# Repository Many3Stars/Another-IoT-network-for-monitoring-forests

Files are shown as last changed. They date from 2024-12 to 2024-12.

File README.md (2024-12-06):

# IoT Monitoring System for Forest Environments

Author: Manuel Álvarez Herrera  
Supervisor: José Antonio García Souto  
Year: 2024

## Abstract

This project implements an IoT system to monitor forest environments, particularly coniferous and oak forests, aiming to study the effects of climate change. The IoT network consists of sensor nodes, intermediate nodes, and a database, enabling the collection and analysis of environmental and tree health data.

## Objectives

The primary objective is to observe the impact of climate change on trees by collecting relevant data such as temperature, humidity, solar radiation, and other key indicators.

## Technologies Used

- **Hardware:** Arduino, Raspberry Pi, Dragino NBSN95, LSN50, temperature, humidity sensors, and more.
- **Communication Protocols:** LoRa, NB-IoT, WiFi.
- **Databases:** InfluxDB, ThingsBoard, Home Assistant.
- **Weather Stations:** Ecowitt, Wunderground, Weathercloud.

## IoT Network Structure

1. **Sensor Node A:** Arduino Uno, Raspberry Pi 4 B, sensors for foliage and soil.
2. **Sensor Node B:** Dragino NBSN95 and LSN50 devices.
3. **Sensor Node C:** Sainlogic WS3500 weather station.

## Results

The system was successfully tested in a controlled environment, obtaining accurate data for forest environment analysis. The tests demonstrated the system's viability for monitoring remote forests.

## Conclusion

The designed IoT system is scalable, energy-efficient, and adaptable to various environments, including farms and urban forest areas.

## Repository

The code and additional documentation are available in the following GitHub repository:  
[Another IoT network for monitoring forests](https://github.com/Many3Stars/IoT-network-for-monitoring-forests)

## References

1. K. Raviteja, M. Supriya, "IoT-Based Agriculture Monitoring System", Springer, 2020.
2. N. Suma, S. Samson, "Recent Innovations in Computing and Communication", 2021.
3. Kazuho M., Takeshi O., "Dependence of Stomatal Conductance on Leaf Chlorophyll Concentration", 2025.

---

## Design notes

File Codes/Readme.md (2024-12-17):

# Codes

This directory contains the source codes for the two types of sensor nodes used in the IoT monitoring system for forest environments: **Sensor Node A** and **Sensor Node B**. These nodes handle data acquisition, preprocessing, and transmission to the IoT network.

---

## Sensor Nodes Overview

### **Sensor Node A**
- **Functionality:** 
  - This node is designed to acquire and process data from various sensors.
  - The sensors are connected to an Arduino Uno, which handles data acquisition and preprocessing.
  - The processed data is then transmitted to a Raspberry Pi 4 B, which:
    - Powers the sensors.
    - Temporarily stores the data in a JSON file.
    - Transmits the data via LoRa communication to the IoT network.
- **Communication Protocol:** LoRa (long-range, low-power communication).
- **Use Case:** Suitable for applications requiring robust communication over long distances in remote environments.

### **Sensor Node B**
- **Functionality:**
  - This node uses Dragino devices (NBSN95 and LSN50) for data acquisition, preprocessing, and transmission.
  - Each device serves a specific purpose:
    - **NBSN95:** Transmits data via NB-IoT, leveraging GSM networks for mobile communication.
    - **LSN50:** Transmits data via LoRa for long-distance communication.
  - These nodes are compact and support plug-and-play operation, ideal for rapid deployment.
- **Communication Protocols:** 
  - NB-IoT (NBSN95)
  - LoRa (LSN50)
- **Use Case:** Versatile for environments with varying communication infrastructure.

---

## Folder Structure

### **Sensor_Node_A**
- Contains the source code for Sensor Node A.
- Key Features:
  - Arduino sketch for data acquisition and preprocessing.
  - Raspberry Pi scripts for:
    - JSON-based temporary data storage.
    - Transmission using LoRa communication.
  - Power management routines for efficient operation.

### **Sensor_Node_B**
- Contains the source code for Sensor Node B.
- Key Features:
  - Firmware for Dragino NBSN95 and LSN50 devices.
  - Configurations for sensor data acquisition and transmission.
  - NB-IoT and LoRa-specific implementations for data handling.

---

## How to Use

1. **Select the Appropriate Node:**
   - Use **Sensor Node A** for scenarios requiring detailed control via Arduino and Raspberry Pi.
   - Use **Sensor Node B** for rapid deployment with Dragino devices.

2. **Upload the Code:**
   - For Sensor Node A:
     - Upload the Arduino sketch to the Arduino Uno.
     - Deploy the Raspberry Pi scripts.
   - For Sensor Node B:
     - Configure and upload the firmware to the NBSN95 and LSN50 devices.

3. **Test the Nodes:**
   - Verify sensor data acquisition and preprocessing.
   - Ensure successful data transmission via the appropriate protocol (LoRa or NB-IoT).

---

## Notes

- Ensure all hardware components are correctly connected and powered before uploading the code.
- Customize the configuration files as needed for your specific sensors and deployment environment.
- Detailed instructions for setting up and calibrating the nodes can be found in the respective subfolders.

---

## Support

If you encounter issues or have questions:
- Refer to the comments in the code for additional guidance.
- Open an issue in this repository or contact the repository maintainer for further assistance.

---

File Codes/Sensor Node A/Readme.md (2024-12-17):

# Sensor Node A

This folder contains the code and configurations for **Sensor Node A**, which is responsible for data acquisition, preprocessing, and transmission in the IoT monitoring system for forest environments.

---

## Overview

**Sensor Node A** integrates two primary components:

1. **Arduino Uno**:  
   - Acquires and preprocesses data from connected sensors (e.g., soil and leaf sensors).  
   - Processes sensor readings and prepares them for transmission.  
   - Communicates with the Raspberry Pi via I2C.

2. **Raspberry Pi 4 B**:  
   - Receives the preprocessed data from the Arduino over an I2C connection.  
   - Temporarily stores the data in a JSON format.  
   - Transmits the data to the IoT network using an external LoRa communication module.

This architecture ensures efficient handling of data while leveraging the long-range capabilities of LoRa communication for remote deployments.

---

## Key Features

- **I2C Communication**:  
  The Arduino sends preprocessed sensor data to the Raspberry Pi via an I2C interface, ensuring a reliable and simple data transfer method.

- **LoRa Transmission**:  
  The Raspberry Pi uses an external LoRa module to transmit the collected data over long distances. This is ideal for remote environments with limited connectivity.

- **Power Management**:  
  The system includes routines to minimize power consumption, such as turning off sensors when not in use.

---

## Folder Structure

- `arduino/`: Contains the Arduino sketch for:
  - Data acquisition from sensors.
  - Preprocessing and sending data to the Raspberry Pi via I2C.

- `raspberry_pi/`: Contains Python scripts for:
  - Receiving data over I2C.
  - Formatting and storing data in JSON files.
  - Transmitting data using the external LoRa communication module.

---

## How to Use

1. **Arduino Setup**:
   - Open the Arduino sketch from the `arduino/` folder.
   - Upload it to the Arduino Uno.
   - Ensure sensors are properly connected to the Arduino.

2. **Raspberry Pi Setup**:
   - Install the necessary Python dependencies listed in the `requirements.txt` (if provided).
   - Run the Raspberry Pi scripts to:
     - Initialize the I2C connection.
     - Manage data storage and LoRa transmission.

3. **Hardware Connections**:
   - Connect the Arduino and Raspberry Pi via I2C:
     - **Arduino SDA (A4)** → **Raspberry Pi SDA (GPIO2)**  
     - **Arduino SCL (A5)** → **Raspberry Pi SCL (GPIO3)**  
   - Ensure the LoRa module is properly connected to the Raspberry Pi.

4. **Run the System**:
   - Power on the devices and verify that:
     - The Arduino is acquiring sensor data and sending it over I2C.
     - The Raspberry Pi is successfully receiving the data and transmitting it via LoRa.

---

## Notes

- The external LoRa module must be configured correctly for the desired frequency and region.
- Ensure that both the Arduino and Raspberry Pi share a common ground (GND) for proper I2C communication.

---

## Troubleshooting

- **No I2C Communication:** 
  - Verify SDA and SCL connections.
  - Ensure the I2C interface is enabled on the Raspberry Pi.

- **LoRa Transmission Issues:** 
  - Check the LoRa module configuration and ensure it matches the receiver settings.
  - Verify the antenna is securely attached to the LoRa module.

---

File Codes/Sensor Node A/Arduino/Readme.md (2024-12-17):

# Arduino

This folder contains the Arduino sketches used in **Sensor Node A** for data acquisition and preprocessing. The sketches are designed to support two operation modes: continuous data acquisition (Mode 1) and periodic data acquisition with advanced averaging techniques (Mode 2).

---

## Modes of Operation

### **Mode 1: Continuous Data Acquisition**
- **Description**:
  - In this mode, the Arduino continuously powers the sensors and acquires data without interruption.
  - The Raspberry Pi remains active and periodically requests the acquired data via I2C.
- **Use Case**:
  - Ideal for scenarios requiring real-time or near-real-time monitoring.

### **Mode 2: Periodic Data Acquisition with Power Management**
- **Description**:
  - In this mode, the system enters a low-power state between data acquisition intervals.
  - The Raspberry Pi powers down the sensors and itself, then wakes up periodically to acquire data.
  - Data is processed using either a **Trimmed Mean** or a **Winsorized Mean** to reduce the impact of noise and outliers.
  - After processing, the Arduino sends the data to the Raspberry Pi over I2C, and the Raspberry Pi transmits it using LoRa.
- **Use Case**:
  - Ideal for power-constrained environments where energy efficiency is critical.

---

## Arduino Sketches

1. **Mode_1_Continuous_Data_Acquisition.ino**
   - Implements continuous data acquisition.
   - The Arduino constantly acquires data from the sensors.
   - Responds to requests from the Raspberry Pi to send the data via I2C.

2. **Mode_1_Data_Acquisition_when_it_receives_request_from_Rasp.ino**
   - Similar to the first sketch, but data acquisition is triggered only when the Raspberry Pi sends a request.
   - Useful for reducing unnecessary sensor activity.

3. **Mode_2_Periodic_Acquisition_Trimmed_Mean.ino**
   - Implements periodic data acquisition with power management.
   - Processes acquired data using a **Trimmed Mean**, which discards extreme values to reduce the influence of outliers.

4. **Mode_2_Periodic_Acquisition_Winsorized_Mean.ino**
   - Similar to the previous sketch but processes data using a **Winsorized Mean**, which limits extreme values to reduce noise while retaining the original data structure.

---

## How It Works

1. **Sensor Activation**:
   - In **Mode 1**, sensors are always powered.
   - In **Mode 2**, sensors are activated only during the data acquisition period.

2. **Data Processing**:
   - The Arduino preprocesses the sensor data using the selected mode:
     - Continuous data stream (Mode 1).
     - Trimmed or Winsorized mean calculation (Mode 2).

3. **I2C Communication**:
   - The Arduino sends the processed data to the Raspberry Pi via I2C upon request.

4. **LoRa Transmission**:
   - The Raspberry Pi handles the transmission of the processed data via LoRa.

---

## How to Use

1. **Select the Desired Mode**:
   - Choose the appropriate sketch based on your use case (continuous or periodic data acquisition).

2. **Upload the Sketch**:
   - Open the selected `.ino` file in the Arduino IDE.
   - Upload it to the Arduino Uno.

3. **Configure the Raspberry Pi**:
   - Ensure the Raspberry Pi is configured to match the selected mode:
     - **Mode 1**: Continuous or on-request data acquisition.
     - **Mode 2**: Periodic data collection with power management.

4. **Test the System**:
   - Verify sensor readings and data transmission.
   - Check that the Raspberry Pi and Arduino communicate properly over I2C.

---

## Notes

- **Power Efficiency**:
  - Mode 2 significantly reduces power consumption by deactivating sensors and the Raspberry Pi between acquisition cycles.
  - Use this mode for long-term deployments in remote areas.

- **Data Integrity**:
  - Advanced processing methods (Trimmed and Winsorized Means) in Mode 2 ensure robust data quality by minimizing the impact of noise and outliers.

---

## Troubleshooting

- **I2C Communication Issues**:
  - Verify the wiring between the Arduino and Raspberry Pi (SDA/SCL connections).
  - Ensure the Raspberry Pi's I2C interface is enabled.

- **Unexpected Data Values**:
  - Check sensor connections and calibration.
  - Validate the averaging method used in Mode 2.

---

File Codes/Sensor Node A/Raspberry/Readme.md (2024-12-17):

 # Raspberry

This folder contains the scripts and configurations used by the Raspberry Pi in **Sensor Node A**. The Raspberry Pi plays a crucial role in managing data communication between the Arduino and the IoT network.

---

## Functionality

The Raspberry Pi handles the following tasks:

1. **Requesting Data from Arduino**:  
   - The Raspberry Pi sends periodic requests to the Arduino over the I2C interface.  
   - The Arduino responds with the preprocessed sensor data.

2. **Storing Data in JSON Format**:  
   - The received data is stored locally in a JSON file as a backup.  
   - This ensures data is not lost if the LoRa connection fails temporarily.

3. **Transmitting Data via LoRa**:  
   - The Raspberry Pi uses an external LoRa communication module to send the sensor data to the IoT network.  
   - LoRa provides long-range, low-power communication ideal for remote monitoring.

--- 

## How It Works

1. **I2C Communication**:
   - The Raspberry Pi acts as an I2C master, sending requests to the Arduino (I2C slave).
   - Data exchange format:
     - **Request:** A simple command from the Raspberry Pi to trigger data transmission.
     - **Response:** The Arduino sends sensor readings in a structured format.

2. **Data Backup**:
   - After receiving the data, the Raspberry Pi writes it to a local JSON file.
   - This file acts as a backup, allowing recovery of data if the LoRa transmission fails.

3. **LoRa Transmission**:
   - The Raspberry Pi formats the data for LoRa transmission.
   - It sends the data using the external LoRa module, ensuring it reaches the IoT network even in remote environments.

---

## Notes

- **Backup and Resilience**:
  - JSON backups ensure data integrity in case of transmission failures.
  - These files can be uploaded manually to the IoT network if needed.

- **LoRa Module**:
  - Ensure the LoRa module is configured correctly for the region and frequency.
  - Check that the antenna is securely attached for optimal signal strength.

---

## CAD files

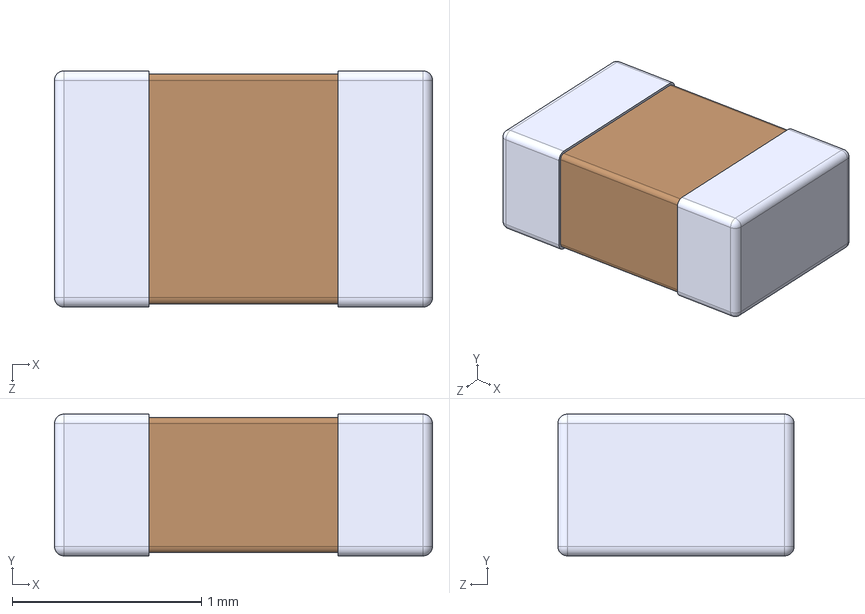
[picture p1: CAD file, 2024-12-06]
PCB_Manufacturing_Sheets/Components/CL21B103KBANNNC/CL21B103KBANNNC.step
2.00 x 0.75 x 1.25 mm

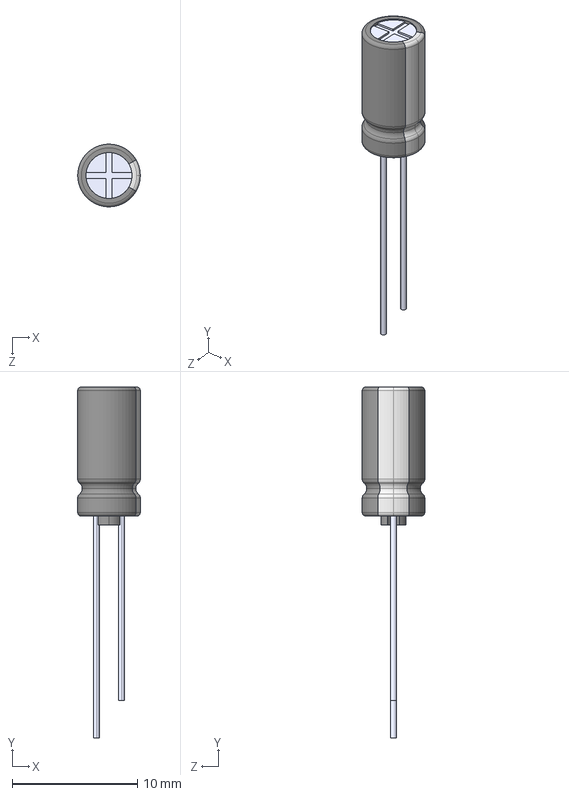
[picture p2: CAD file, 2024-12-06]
PCB_Manufacturing_Sheets/Components/EEUFC1H150/EEU-FC1H150.STEP
5.00 x 28.0 x 4.99 mm

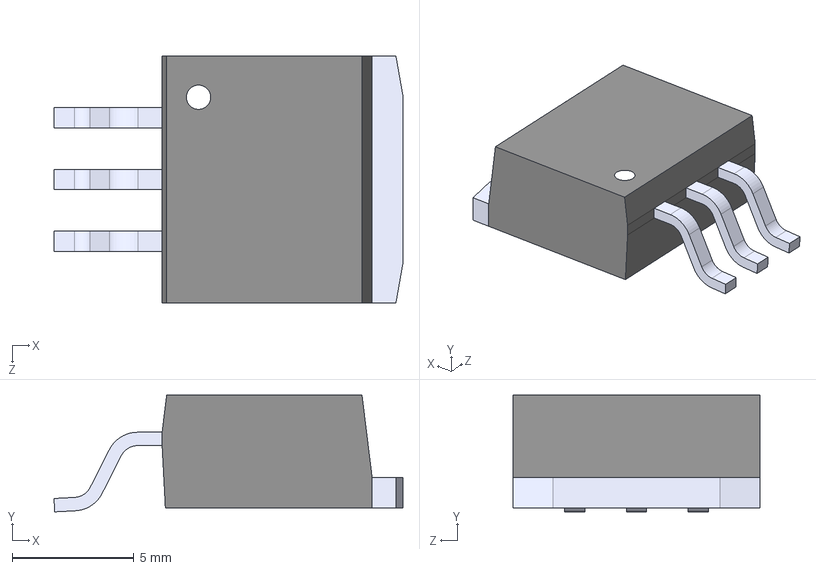
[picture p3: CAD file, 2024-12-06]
PCB_Manufacturing_Sheets/Components/LM1085ISX-5.0_NOPB/LM1085ISX-5.0_NOPB.step
14.4 x 4.80 x 10.2 mm

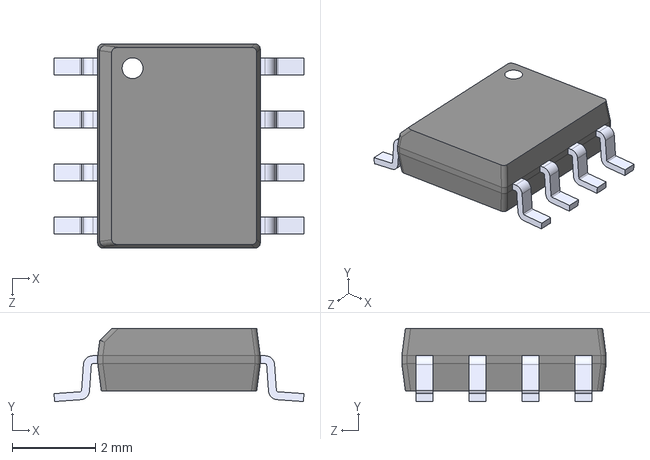
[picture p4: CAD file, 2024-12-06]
PCB_Manufacturing_Sheets/Components/LM317LID/LM317LID.step
5.99 x 1.75 x 4.90 mm

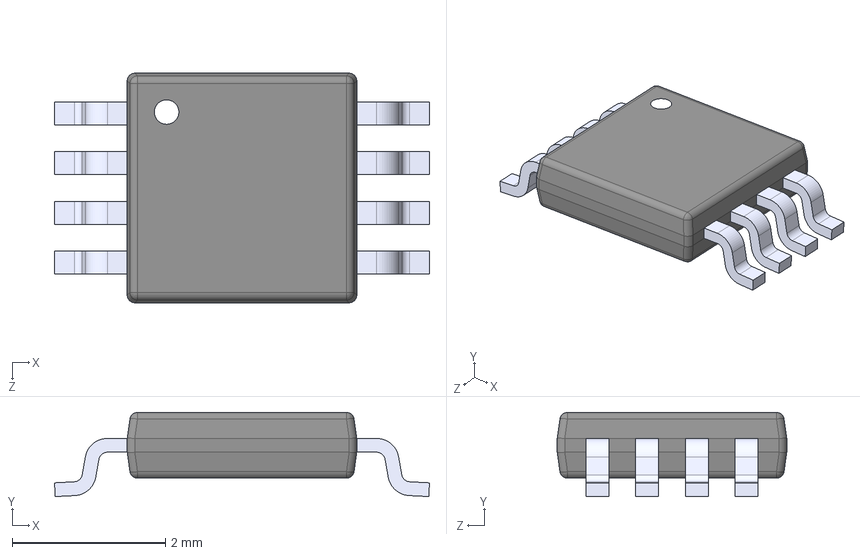
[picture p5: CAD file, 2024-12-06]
PCB_Manufacturing_Sheets/Components/LT5400BCMS8E-6_PBF/LT5400BCMS8E-6_PBF.step
4.90 x 1.10 x 3.00 mm

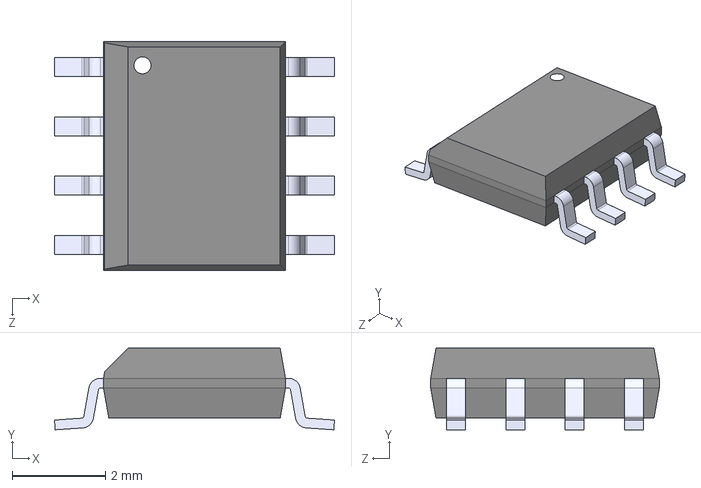
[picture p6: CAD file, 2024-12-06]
PCB_Manufacturing_Sheets/Components/OP292GSZ-REEL/OP292GSZ-REEL.step
6.00 x 1.75 x 4.90 mm

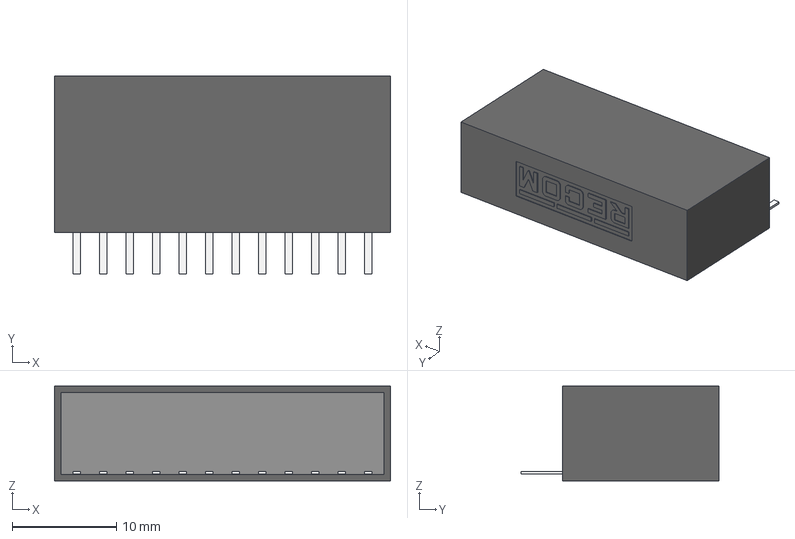
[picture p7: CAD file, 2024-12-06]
PCB_Manufacturing_Sheets/Components/R-739.0P/R-739.0P.step
32.2 x 19.0 x 9.10 mm

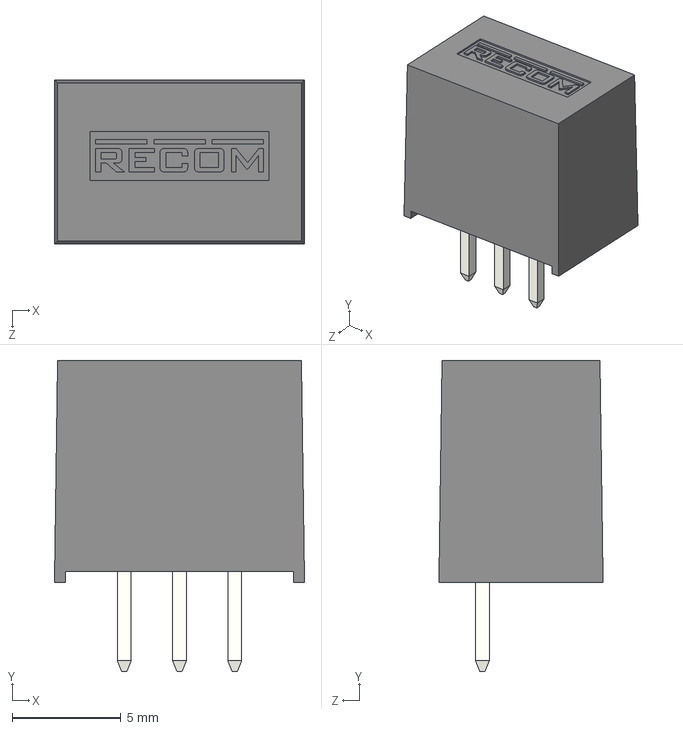
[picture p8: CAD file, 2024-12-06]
PCB_Manufacturing_Sheets/Components/R-78K2.5-1.0/R-78K2.5-1.0.step
11.5 x 14.3 x 7.55 mm

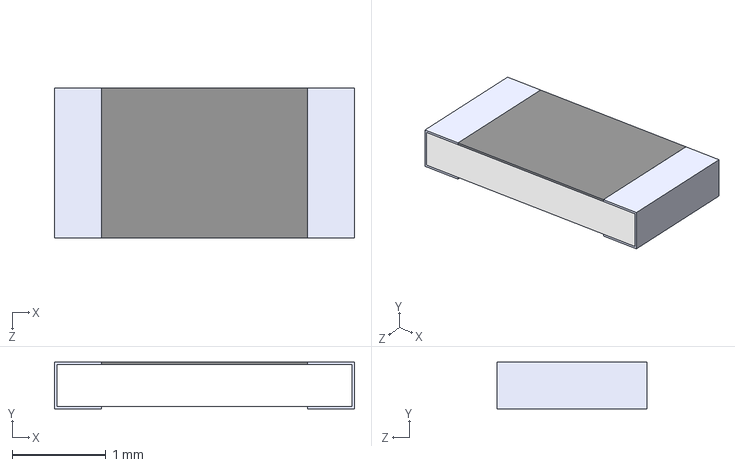
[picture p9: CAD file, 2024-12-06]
PCB_Manufacturing_Sheets/Components/RG3216P-1000-B-T1/RG3216P-1000-B-T1.step
3.20 x 0.5 x 1.60 mm

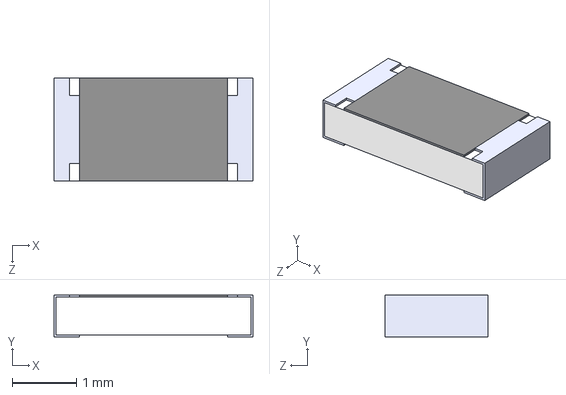
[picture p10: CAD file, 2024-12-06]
PCB_Manufacturing_Sheets/Components/RT1206BRD07300RL/RT1206BRD07300RL.step
3.10 x 0.65 x 1.60 mm

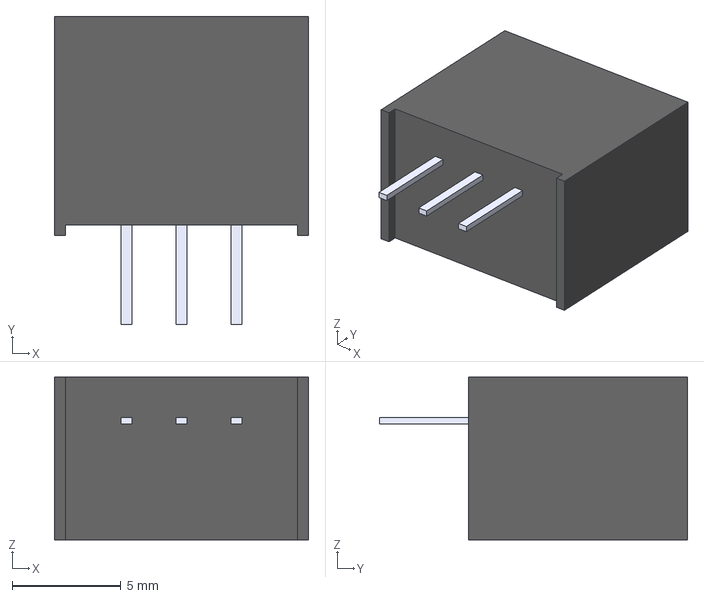
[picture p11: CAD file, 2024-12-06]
PCB_Manufacturing_Sheets/Components/VR05S(TSR1-2490)/TSR1-2490.step
11.7 x 14.2 x 7.50 mm

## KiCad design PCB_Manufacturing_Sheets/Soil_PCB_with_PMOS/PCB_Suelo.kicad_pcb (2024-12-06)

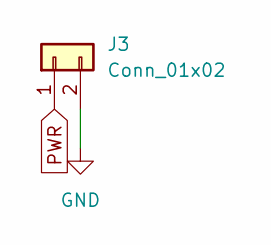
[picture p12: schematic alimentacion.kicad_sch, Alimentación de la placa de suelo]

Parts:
J3: Conn_01x02; PinHeader_1x02_P2.54mm_Vertical

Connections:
GND: J3.2; also elsewhere on the board
PWR: J3.1; also elsewhere on the board

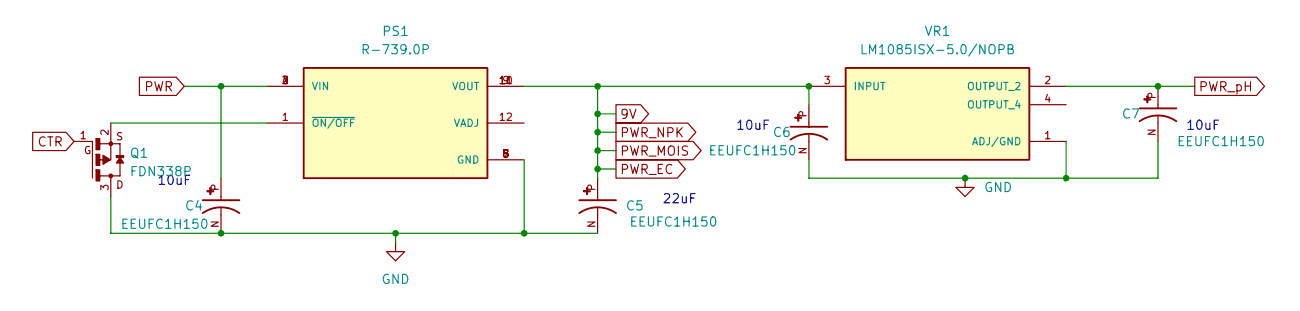
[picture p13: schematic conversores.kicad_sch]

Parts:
C4, C5, C6, C7: EEUFC1H150; CAPPRD200W50D500H1100; PARTREV 20-DEC-19
PS1: R-739.0P; CONV_R-739.0P; PARTREV 5
Q1: FDN338P; SSOT-3
VR1: LM1085ISX-5.0/NOPB; TO254P1435X464-4N; PARTREV I

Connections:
9V: C5.P, C6.P, PS1.9 (VOUT), PS1.10 (VOUT), PS1.11 (VOUT), VR1.3 (INPUT); also elsewhere on the board
CTR: Q1.1; also elsewhere on the board
GND: C4.N, C5.N, C6.N, C7.N, PS1.5 (GND), PS1.6 (GND), PS1.7 (GND), PS1.8 (GND), Q1.3, VR1.1 (ADJ/GND); also elsewhere on the board
unnamed: PS1.1 (~ON/OFF), Q1.2
PWR: C4.P, PS1.2 (VIN), PS1.3 (VIN), PS1.4 (VIN); also elsewhere on the board
PWR_pH: C7.P, VR1.2 (OUTPUT_2); also elsewhere on the board

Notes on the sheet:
10uF
22uF

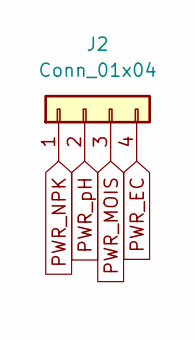
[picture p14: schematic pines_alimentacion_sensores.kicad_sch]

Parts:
J2: Conn_01x04; PinHeader_1x04_P2.54mm_Vertical

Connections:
9V: J2.1, J2.3, J2.4; also elsewhere on the board
PWR_pH: J2.2; also elsewhere on the board

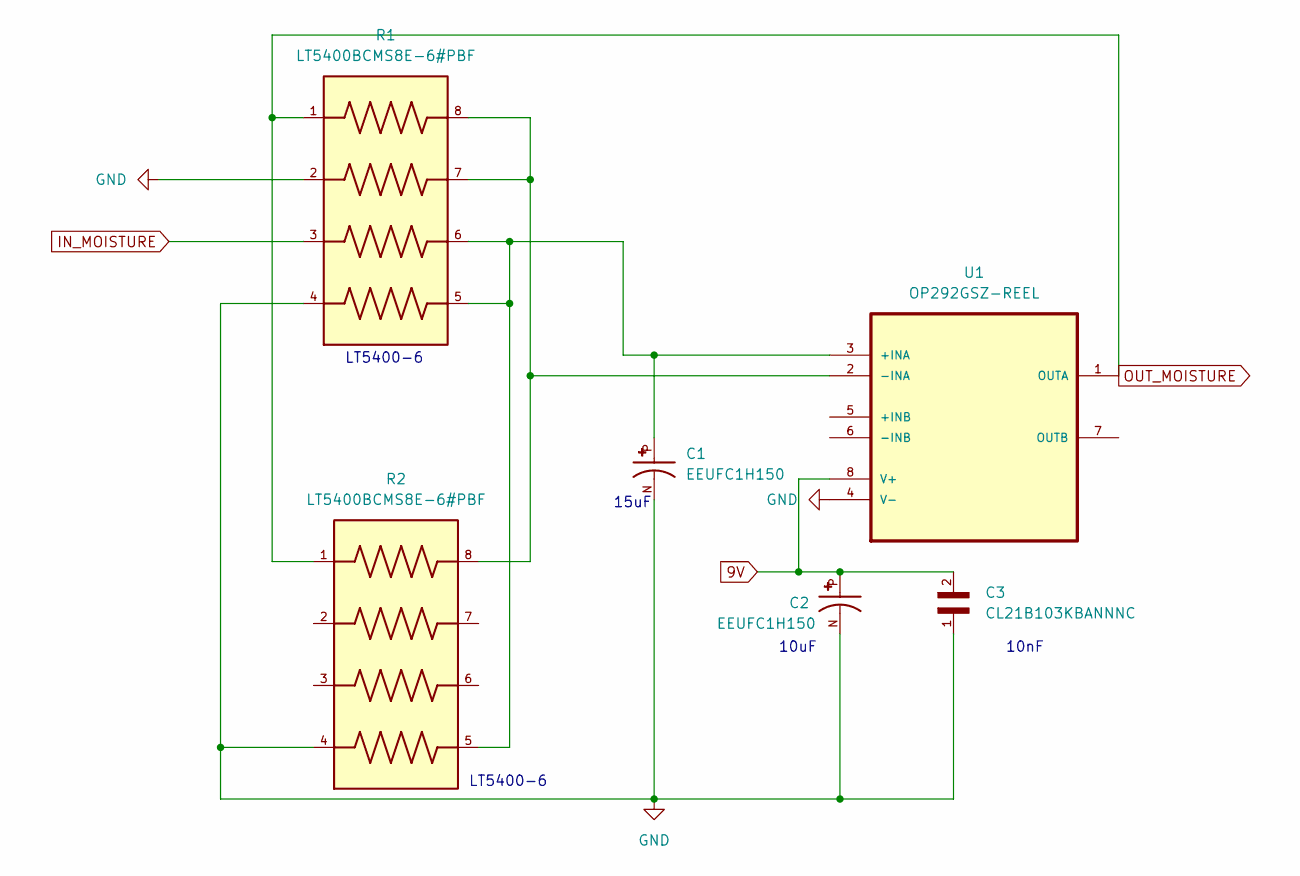
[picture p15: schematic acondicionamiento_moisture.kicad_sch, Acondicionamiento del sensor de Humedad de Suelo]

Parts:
C1, C2: EEUFC1H150; CAPPRD200W50D500H1100; PARTREV 20-DEC-19
C3: CL21B103KBANNNC; CAPC2012X140N
R1, R2: LT5400BCMS8E-6#PBF; SOP65P490X110-9N; PARTREV I
U1: OP292GSZ-REEL; SOIC127P600X175-8N; MPN OP292GSZ-REEL

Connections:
9V: C2.P, C3.2, U1.8 (V+); also elsewhere on the board
GND: C1.N, C2.N, C3.1, R1.2, R1.4, R2.4, U1.4 (V-); also elsewhere on the board
IN_MOISTURE: R1.3; also elsewhere on the board
unnamed: C1.P, R1.5, R1.6, R2.5, U1.3 (+INA)
unnamed: R1.7, R1.8, R2.8, U1.2 (-INA)
OUT_MOISTURE: R1.1, R2.1, U1.1 (OUTA); also elsewhere on the board

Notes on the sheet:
10nF
LT5400-6
10uF
15uF

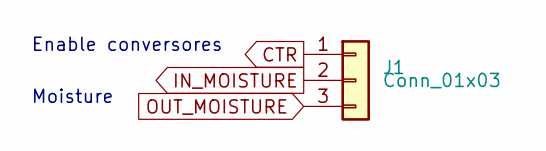
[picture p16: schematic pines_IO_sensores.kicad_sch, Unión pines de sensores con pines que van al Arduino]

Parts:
J1: Conn_01x03; PinHeader_1x03_P2.54mm_Vertical

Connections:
CTR: J1.1; also elsewhere on the board
IN_MOISTURE: J1.2; also elsewhere on the board
OUT_MOISTURE: J1.3; also elsewhere on the board

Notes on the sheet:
Moisture
Enable conversores

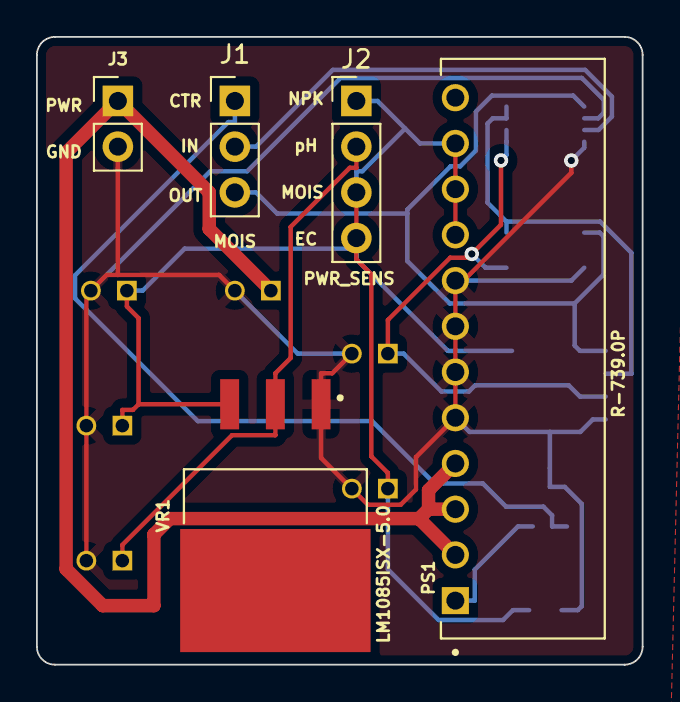
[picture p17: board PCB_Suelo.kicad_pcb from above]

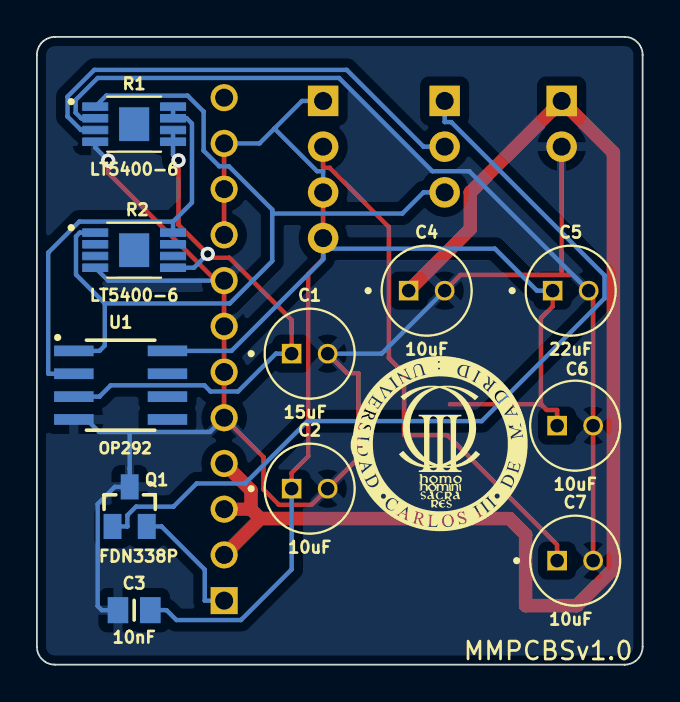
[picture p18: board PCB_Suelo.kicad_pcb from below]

Board: 2 copper layers, 33.7 x 34.9 mm, 17 parts (12 on the bottom side), 10 nets.

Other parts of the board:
G: L; Logo2

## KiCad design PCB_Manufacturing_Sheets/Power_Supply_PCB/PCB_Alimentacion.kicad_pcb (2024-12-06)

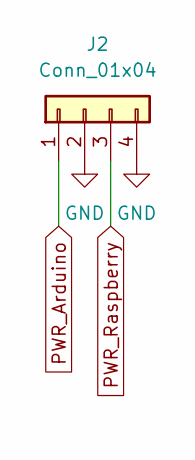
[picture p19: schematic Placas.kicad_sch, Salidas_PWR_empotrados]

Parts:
J2: Conn_01x04; PinHeader_1x04_P2.54mm_Vertical

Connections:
GND: J2.2, J2.4; also elsewhere on the board
PWR_Arduino: J2.1; also elsewhere on the board
PWR_Raspberry: J2.3; also elsewhere on the board

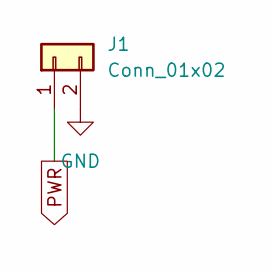
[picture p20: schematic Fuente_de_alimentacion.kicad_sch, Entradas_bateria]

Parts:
J1: Conn_01x02; PinHeader_1x02_P2.54mm_Vertical

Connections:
GND: J1.2; also elsewhere on the board
PWR: J1.1; also elsewhere on the board

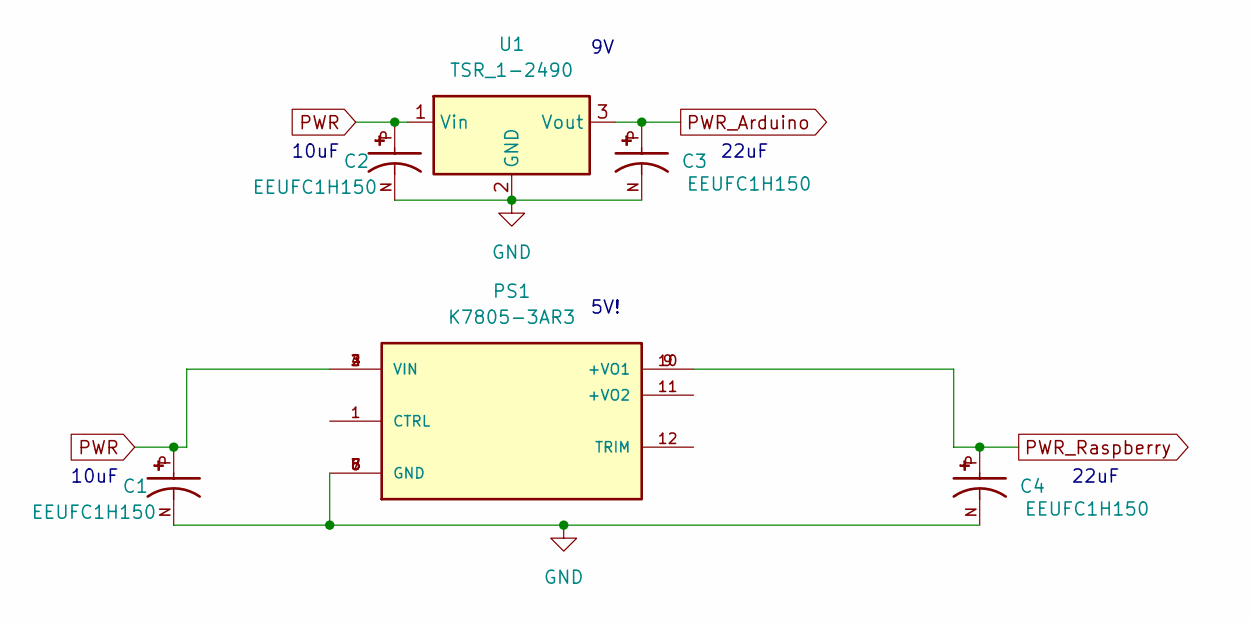
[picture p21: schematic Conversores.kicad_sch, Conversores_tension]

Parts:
C1, C2, C3, C4: EEUFC1H150; CAPPRD200W50D500H1100; PARTREV 20-DEC-19
PS1: K7805-3AR3; CONV_K7805-3AR3; PARTREV 2021.01.29-A/2
U1: TSR_1-2490; Converter_DCDC_TRACO_TSR-1_THT

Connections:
GND: C1.N, C2.N, C3.N, C4.N, PS1.5 (GND), PS1.6 (GND), PS1.7 (GND), PS1.8 (GND), U1.2 (GND); also elsewhere on the board
PWR: C1.P, C2.P, PS1.2 (VIN), PS1.3 (VIN), PS1.4 (VIN), U1.1 (Vin); also elsewhere on the board
PWR_Arduino: C3.P, U1.3 (Vout); also elsewhere on the board
PWR_Raspberry: C4.P, PS1.9 (+VO1), PS1.10 (+VO1); also elsewhere on the board

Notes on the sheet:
22uF
10uF
5V!

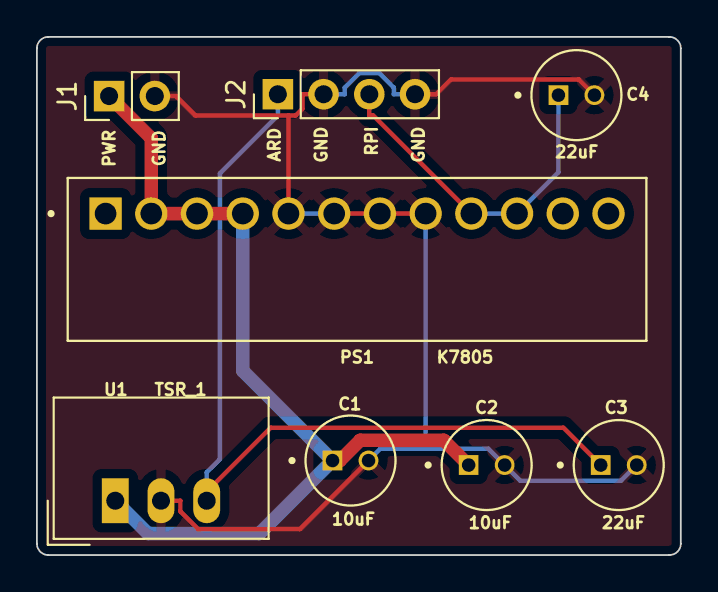
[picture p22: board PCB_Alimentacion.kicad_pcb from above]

Board: 2 copper layers, 35.8 x 28.8 mm, 9 parts (1 on the bottom side), 4 nets.

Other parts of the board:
G: L; Logo2

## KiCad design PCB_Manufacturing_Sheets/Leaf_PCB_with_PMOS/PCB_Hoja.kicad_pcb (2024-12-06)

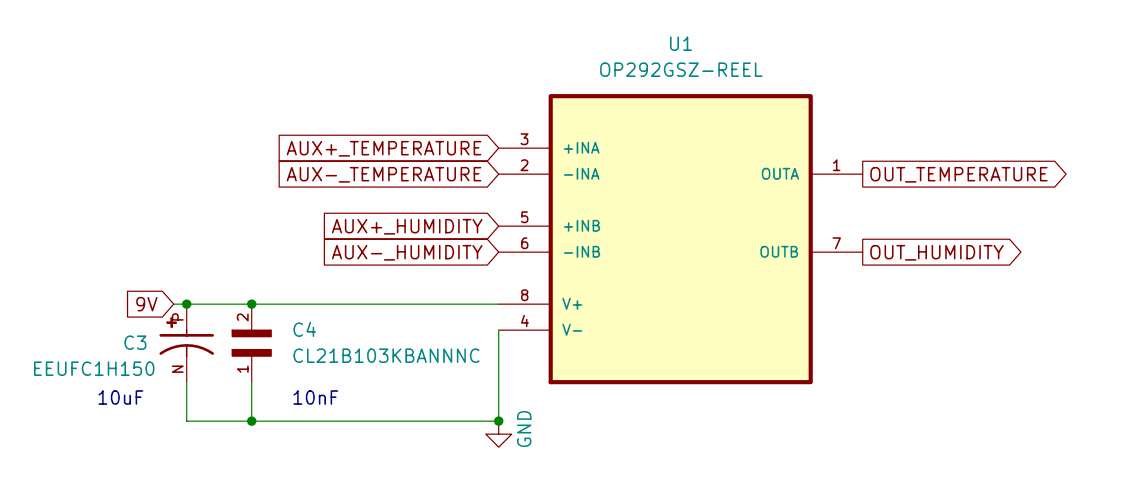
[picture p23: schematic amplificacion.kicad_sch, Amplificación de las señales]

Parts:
C3: EEUFC1H150; CAPPRD200W50D500H1100; PARTREV 20-DEC-19
C4: CL21B103KBANNNC; CAPC2012X140N
U1: OP292GSZ-REEL; SOIC127P600X175-8N; MPN OP292GSZ-REEL

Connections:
9V: C3.P, C4.2, U1.8 (V+); also elsewhere on the board
AUX+_HUMIDITY: U1.5 (+INB); also elsewhere on the board
AUX+_TEMPERATURE: U1.3 (+INA); also elsewhere on the board
AUX-_HUMIDITY: U1.6 (-INB); also elsewhere on the board
AUX-_TEMPERATURE: U1.2 (-INA); also elsewhere on the board
GND: C3.N, C4.1, U1.4 (V-); also elsewhere on the board
OUT_HUMIDITY: U1.7 (OUTB); also elsewhere on the board
OUT_TEMPERATURE: U1.1 (OUTA); also elsewhere on the board

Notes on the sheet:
10nF
10uF


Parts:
J2, J3: Conn_01x02; PinHeader_1x02_P2.54mm_Vertical

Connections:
IN_HUMIDITY: J2.1; also elsewhere on the board
IN_TEMPERATURE: J2.2; also elsewhere on the board
OUT_HUMIDITY: J3.2; also elsewhere on the board
OUT_TEMPERATURE: J3.1; also elsewhere on the board

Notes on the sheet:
Humidity
Temperature


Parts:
C2: EEUFC1H150; CAPPRD200W50D500H1100; PARTREV 20-DEC-19
R3: LT5400BCMS8E-6#PBF; SOP65P490X110-9N; PARTREV I

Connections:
AUX+_HUMIDITY: C2.P, R3.5, R3.6; also elsewhere on the board
AUX-_HUMIDITY: R3.7, R3.8; also elsewhere on the board
GND: C2.N, R3.2, R3.4; also elsewhere on the board
IN_HUMIDITY: R3.3; also elsewhere on the board
OUT_HUMIDITY: R3.1; also elsewhere on the board

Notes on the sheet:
LT5400-7
15uF


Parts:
C5, C6: CL21B103KBANNNC; CAPC2012X140N
R4: LT5400BCMS8E-6#PBF; SOP65P490X110-9N; PARTREV I
U2: LM317LID; SOIC127P599X175-8N
U3: LM358DR2G; SOIC127P600X175-8N

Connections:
0.25V: U3.1 (AOUT), U3.2 (AIN-); also elsewhere on the board
9V: C5.1, U2.1 (IN), U3.8 (VCC); also elsewhere on the board
GND: C5.2, C6.2, R4.2, U2.4 (ADJUSTMENT), U3.4 (GND); also elsewhere on the board
unnamed: C6.1, R4.1, U2.2 (OUT), U2.3 (OUT), U2.6 (OUT), U2.7 (OUT)
unnamed: R4.7, R4.8, U3.3 (AIN+)

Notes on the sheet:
1uF
0.25V
0.1uF
LT5400-7
1.25V


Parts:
C1: CL21B103KBANNNC; CAPC2012X140N
R1, R2: LT5400BCMS8E-6#PBF; SOP65P490X110-9N; PARTREV I

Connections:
0.25V: R1.8; also elsewhere on the board
AUX+_TEMPERATURE: C1.1, R1.6, R2.3, R2.4; also elsewhere on the board
AUX-_TEMPERATURE: R1.7, R2.1, R2.2; also elsewhere on the board
GND: C1.2, R2.5, R2.6; also elsewhere on the board
IN_TEMPERATURE: R1.5; also elsewhere on the board
unnamed: R1.1, R1.2
unnamed: R1.3, R1.4
OUT_TEMPERATURE: R2.7, R2.8; also elsewhere on the board

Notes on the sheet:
LT5400-2
LT5400-1
1uF


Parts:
J4: Conn_01x08; PinHeader_1x08_P2.54mm_Vertical

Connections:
GND: J4.2, J4.4, J4.6, J4.8; also elsewhere on the board
PWR_CO2: J4.3, J4.5, J4.7; also elsewhere on the board
PWR_TEMP: J4.1; also elsewhere on the board

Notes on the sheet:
SENSORES HOJA


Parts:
J1: Conn_01x03; PinHeader_1x03_P2.54mm_Vertical

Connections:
CTR: J1.1; also elsewhere on the board
GND: J1.3; also elsewhere on the board
PWR: J1.2; also elsewhere on the board


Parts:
C9, C10, C11, C12, C14, C16: EEUFC1H150; CAPPRD200W50D500H1100; PARTREV 20-DEC-19
C13, C15: CL21B103KBANNNC; CAPC2012X140N
PS1, PS2: R-739.0P; CONV_R-739.0P; PARTREV 5
Q1, Q2: FDN338P; SSOT-3
R5, R6: RG3216P-1000-B-T1; RESC3216X50N
U4: LM317LID; SOIC127P599X175-8N
U5: LM358DR2G; SOIC127P600X175-8N
VR1: LM1085ISX-5.0/NOPB; TO254P1435X464-4N; PARTREV I

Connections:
9V: C11.P, C13.1, PS1.9 (VOUT), PS1.10 (VOUT), PS1.11 (VOUT), U4.1 (IN), U5.8 (VCC); also elsewhere on the board
CTR: Q1.1, Q2.1; also elsewhere on the board
GND: C9.N, C10.N, C11.N, C12.N, C13.2, C14.N, C15.2, C16.N, PS1.5 (GND), PS1.6 (GND), PS1.7 (GND), PS1.8 (GND), PS2.5 (GND), PS2.6 (GND), PS2.7 (GND), PS2.8 (GND), Q1.3, Q2.3, R5.1, U5.4 (GND), VR1.1 (ADJ/GND); also elsewhere on the board
unnamed: C12.P, C14.P, PS2.9 (VOUT), PS2.10 (VOUT), PS2.11 (VOUT), VR1.3 (INPUT)
unnamed: C15.1, R6.2, U4.2 (OUT), U4.3 (OUT), U4.6 (OUT), U4.7 (OUT), U5.3 (AIN+)
unnamed: PS1.1 (~ON/OFF), Q1.2
unnamed: PS2.1 (~ON/OFF), Q2.2
unnamed: R5.2, R6.1, U4.4 (ADJUSTMENT)
PWR: C9.P, C10.P, PS1.2 (VIN), PS1.3 (VIN), PS1.4 (VIN), PS2.2 (VIN), PS2.3 (VIN), PS2.4 (VIN); also elsewhere on the board
PWR_CO2: C16.P, VR1.2 (OUTPUT_2); also elsewhere on the board
PWR_TEMP: U5.1 (AOUT), U5.2 (AIN-); also elsewhere on the board

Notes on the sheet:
10uF
22uF
1uF
0.1uF
100ohm
2.5V

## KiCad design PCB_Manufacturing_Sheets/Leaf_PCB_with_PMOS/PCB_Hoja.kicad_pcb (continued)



Board: 2 copper layers, 55.9 x 35.6 mm, 35 parts (18 on the bottom side), 24 nets.

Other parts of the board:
G: L; Logo2

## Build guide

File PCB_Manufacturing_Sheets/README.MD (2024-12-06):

# PCB Manufacturing Sheets

This folder contains all the necessary schematics and designs for the manufacturing of PCBs related to the data acquisition and power supply of soil and leaf sensors.

## Overview

The designs in this folder are intended to be used with KiCad for PCB design and fabrication. The PCBs are categorized into two primary functions:

- **Power Supply PCBs:** Provide the required voltage levels for sensors and associated circuits.
- **Datalog PCBs:** Handle data acquisition from sensors and ensure reliable data transmission to the Arduino for processing.

### Sensors Supported

1. **Soil Sensors:** Measure parameters like soil humidity, temperature, and pH.
2. **Leaf Sensors:** Measure parameters like leaf humidity, temperature, and stomatal temperature.

---

## Components and Design Highlights

### Key Components
- Voltage regulators for stable power supply.
- PMOS/NMOS transistors for energy-efficient activation/deactivation.
- Circuitry for data acquisition and sensor-specific power requirements.

### PMOS vs NMOS Switching
- **PMOS Design (Recommended):** Low leakage current in the "off" state, ensuring better energy efficiency.
- **NMOS Design:** Functional but with higher leakage current, making it less efficient for long-term applications.

---

## Folder Structure and Details

Each subfolder contains files for a specific PCB design:

### 1. **Power_Supply_PCB**
   - Contains the schematic and PCB layout for the power supply.
   - Includes voltage regulation and distribution for all components.

### 2. **Leaf_PCB_with_NMOS**
   - PCB design for leaf sensors using an NMOS transistor for switching.
   - Measures leaf-related parameters like humidity and temperature.

### 3. **Leaf_PCB_with_PMOS**
   - PCB design for leaf sensors using a PMOS transistor for switching.
   - Optimized for energy efficiency with minimal leakage current.

### 4. **Soil_PCB_with_NMOS**
   - PCB design for soil sensors using an NMOS transistor for switching.
   - Measures soil parameters like humidity, temperature, and pH.

### 5. **Soil_PCB_with_PMOS**
   - PCB design for soil sensors using a PMOS transistor for switching.
   - Designed for low-power consumption and long-term deployments.

---

## Design Recommendations

- **Use PMOS designs for both leaf and soil sensors** to minimize power consumption during standby periods.
- Ensure all components are compatible with the specific voltage and current requirements of your sensors.

---

## How to Use

1. Open the KiCad project files from the respective subfolders.
2. Verify the schematic and PCB design as per your requirements.
3. Export the Gerber files for manufacturing.
4. Assemble the PCB using the components listed in the schematic.

---

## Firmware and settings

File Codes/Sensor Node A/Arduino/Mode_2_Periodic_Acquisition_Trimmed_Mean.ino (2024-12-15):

#include <Wire.h>
#include "DFRobot_OxygenSensor.h"

#define I2C_SLAVE_ADDRESS 0x0B
#define pwmPin 5
#define humPin A0
#define phPin A1

// Variables globales para mantener los valores actualizados
float oxygenData = 0.0;
float humidity_percent = 0.0; // Variable para la humedad relativa en %
float pHValue = 0.0; // Variable para el valor de pH
float ppmAvg = 0.0; // Variable para la media de CO2 durante 30 segundos
unsigned int sampleCount = 0;

// Configuración del sensor de oxígeno
#define Oxygen_IICAddress ADDRESS_3
#define COLLECT_NUMBER 10
DFRobot_OxygenSensor oxygen;

// OFFSET para el sensor de pH
float OFFSET = 0.0; // Ajusta esto según las especificaciones del sensor

// Tanto por ciento del los límites
#define limPercent 40

// Tiempo en que se toman las medidas en ms
#define MEAS_TIME 30000

unsigned long requestStartTime = 0;
bool isDataCollecting = false;

void requestEvent();

float calculateAverage(float values[], int count) {
  // Calcular la media inicial
  float sum = 0.0;
  for (int i = 0; i < count; i++) {
    sum += values[i];
  }
  float initialMean = sum / count;

  // Calcular los límites superior e inferior
  float upperLimit = initialMean * (1.0 + limPercent / 100.0);
  float lowerLimit = initialMean * (1.0 - limPercent / 100.0);

  // Calcular la media truncada
  sum = 0.0;
  int validCount = 0;
  for (int i = 0; i < count; i++) {
    if (values[i] >= lowerLimit && values[i] <= upperLimit) {
      sum += values[i];
      validCount++;
    }
  }

  if (validCount > 0) {
    return sum / validCount;
  } else {
    return initialMean;
  }
}

void resetAverages() {
  for (int i = 0; i < sampleCount; i++) {
    ppmValues[i] = 0.0;
    humidityValues[i] = 0.0;
    oxygenValues[i] = 0.0;
    pHValues[i] = 0.0;
  }
  sampleCount = 0;
}

void setup() {
  Serial.begin(9600);
  pinMode(pwmPin, INPUT);
  Wire.begin(I2C_SLAVE_ADDRESS);
  Wire.onRequest(requestEvent);

  // Inicialización del sensor de oxígeno
  while (!oxygen.begin(Oxygen_IICAddress)) {
    Serial.println("Error al conectar con el sensor de oxígeno.");
    delay(1000);
  }
  Serial.println("Conexión exitosa con el sensor de oxígeno.");
}

void loop() {

  if (isDataCollecting) {
    unsigned long elapsedTime = millis() - requestStartTime;

    long tt = millis();
    int myVal = digitalRead(pwmPin);

    if (myVal == HIGH) {
      if (myVal != prevVal) {
        h = tt;
        tl = h - l;
        prevVal = myVal;
      }
    } else {
      if (myVal != prevVal) {
        l = tt;
        th = l - h;
        prevVal = myVal;
        ppm = 2000 * (th - 2) / (th + tl - 4);
      }
    }

    // Lectura de datos del sensor de oxígeno
    oxygenData = oxygen.getOxygenData(COLLECT_NUMBER);

    // Lectura de humedad y conversión a porcentaje
    int humRaw = analogRead(humPin);
    humidity_percent = map(humRaw, 0, 1023, 0, 100);

    // Lectura del sensor de pH
    int phRaw = analogRead(phPin);
    pHValue = 3.5 * (phRaw / 1023.0) + OFFSET;

    if (elapsedTime >= MEAS_TIME) { // 30 segundos
      // Calcular las medias de cada sensor durante 30 segundos
      float avgCO2 = calculateAverage(ppmValues, sampleCount);
      float avgHumi = calculateAverage(humidityValues, sampleCount);
      float avgOxygen = calculateAverage(oxygenValues, sampleCount);
      float avgPH = calculateAverage(pHValues, sampleCount);

      // Enviar medias por I2C
      byte dataToSend[14];

      // Mostrar valores por pantalla
      Serial.print("Humedad (%): ");
      Serial.println(humidity_percent);
      Serial.print("CO2 (ppm): ");
      Serial.println(ppm);
      Serial.print("Oxígeno (%vol): ");
      Serial.println(oxygenData);
      Serial.print("pH: ");
      Serial.println(pHValue);

      // Enviar datos por I2C
      byte dataToSend[14];
      dataToSend[0] = (int(humidity_percent) >> 8) & 0xFF; // High byte of humidity
      dataToSend[1] = int(humidity_percent) & 0xFF; // Low byte of humidity
      dataToSend[2] = (ppm >> 24) & 0xFF; // Highest byte of CO2
      dataToSend[3] = (ppm >> 16) & 0xFF; // High byte of CO2
      dataToSend[4] = (ppm >> 8) & 0xFF; // Middle byte of CO2
      dataToSend[5] = ppm & 0xFF; // Low byte of CO2
      dataToSend[6] = int(oxygenData); // Valor entero de oxígeno
      dataToSend[7] = int((oxygenData * 10) - int(oxygenData) * 10); // Decimal de oxígeno
      dataToSend[8] = (int(pHValue) >> 8) & 0xFF; // High byte of pH
      dataToSend[9] = int(pHValue) & 0xFF; // Low byte of pH
      dataToSend[10] = int((pHValue - int(pHValue)) * 100); // Parte decimal de pH
      
      Wire.write(dataToSend, sizeof(dataToSend));

      // Reiniciar variables para la siguiente medición
      resetAverages();
      isDataCollecting = false;
    }
  }
}

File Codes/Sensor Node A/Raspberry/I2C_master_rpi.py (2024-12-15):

import smbus
import time
import json
import RPi.GPIO as GPIO

# Configuración del pin GPIO para el activar/desactivar alimentación del Arduino y sensores
ctr_pin = 15
GPIO.setmode(GPIO.BCM)
GPIO.setup(ctr_pin, GPIO.OUT)

# Dirección I2C del Arduino
arduino_address = 0x0B

# Inicialización del bus I2C
bus = smbus.SMBus(1)

# Tiempo en segundos entre peticiones
measurement_time = 10

# Tiempo en segundos entre activar sistema y toma de medida
wakeup_time = 20

def read_data():
    try:
        # Leer 14 bytes de datos desde el Arduino
        data = bus.read_i2c_block_data(arduino_address, 0, 14)
        
        # Decodificar los datos
        humidity_high = data[0]
        humidity_low = data[1]
        co2_high = (data[2] << 24) | (data[3] << 16) | (data[4] << 8) | data[5]
        oxygen_int = data[6]
        oxygen_decimal = data[7]
        ph_high = data[8]
        ph_low = data[9]
        ph_decimal = data[10]

        # Recuperar los valores
        humidity_percent = (humidity_high << 8 | humidity_low)
        co2 = co2_high
        oxygen = f"{oxygen_int*10}.{oxygen_decimal*10}"
        phValue = ((ph_high << 8 | ph_low) + (ph_decimal / 100.0)) * 4

        # Crear un diccionario con los datos
        data_dict = {
            "timestamp": int(time.time()),
            "humidity": humidity_percent,
            "co2": co2,
            "oxygen": oxygen,
            "pH": phValue
        }

        # Obtener la fecha actual (mes y año)
        now = time.localtime()
        file_name = f"{now.tm_mon}_{now.tm_year}.json"

        # Guardar los datos en el archivo de respaldo JSON
        with open(file_name, "a+") as file:
            json.dump(data_dict, file)
            file.write("\n")
            # Guardar los datos a transmitir
            tx_data_file = "tx_data.json"

        with open(tx_data_file, "w") as tx_file:
            json.dump(data_dict, tx_file)

            print("Datos guardados correctamente:")
            print("Humedad (%):", humidity_percent)
            print("CO2 (ppm):", co2)
            print("Oxígeno (%vol):", oxygen)
            print("pH:", phValue)

    except Exception as e:
        print("Error al leer datos:", e)

while True:
    GPIO.output(ctr_pin, GPIO.HIGH)
    time.sleep(wakeup_time) # Tiempo para despertar al sistema
    read_data()
    time.sleep(1)
    GPIO.output(ctr_pin, GPIO.LOW)
    time.sleep(measurement_time) # Esperar 20 minutos entre cada lectura
